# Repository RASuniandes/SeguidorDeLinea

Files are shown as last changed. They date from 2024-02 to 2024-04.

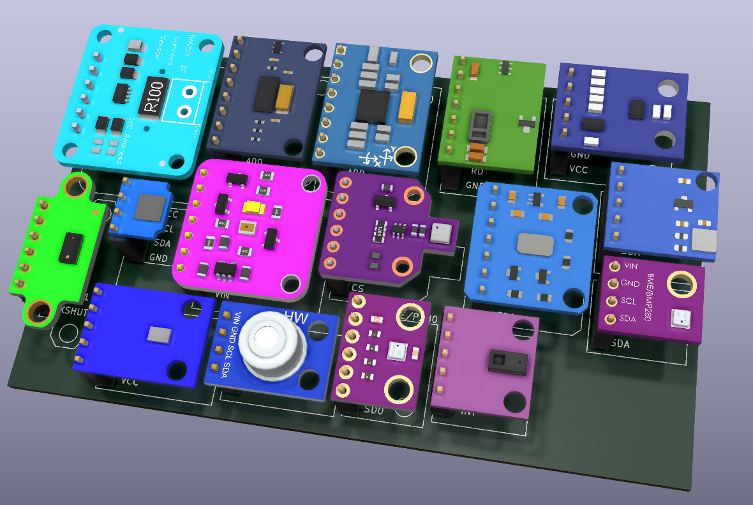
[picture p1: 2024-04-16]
PCB/librerias/librerias/usini_kicad_sensors-main/usini_kicad_sensors-main/sources/images/3D.png

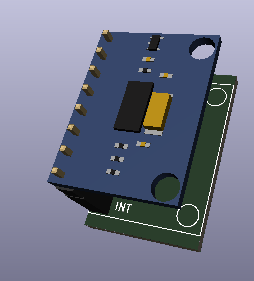
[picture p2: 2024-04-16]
PCB/librerias/librerias/usini_kicad_sensors-main/usini_kicad_sensors-main/sources/fusion360/adxl345.png

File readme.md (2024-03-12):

# Seguidor de linea
## Equipo 2024-1:
- Sergio Mora (SerAle25)
- Mateo López (Mateo-Lopez83)
- Alejandro Alvernia (AlejandroAAL)
- Laura Avelino (Lauraavelin)
- Valentina Romo ()
- Juan Felipe Ángulo (JuanFelipeAngulo)
- Mariana Vanoy (i4d1luc)
En rotación Valentina Arenas (Con interés de aprender temas de diseño mecánico e IMEC)

**Este es el equipo para 2024-1**

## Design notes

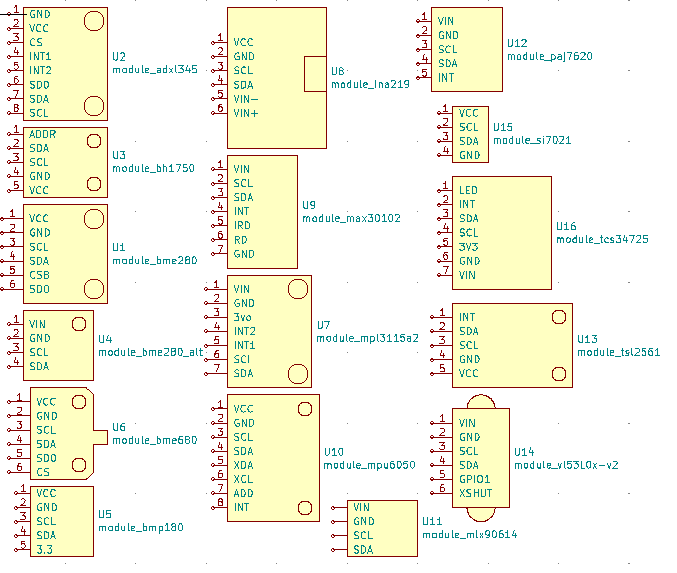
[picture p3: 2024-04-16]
PCB/librerias/librerias/usini_kicad_sensors-main/usini_kicad_sensors-main/sources/images/schematics.png

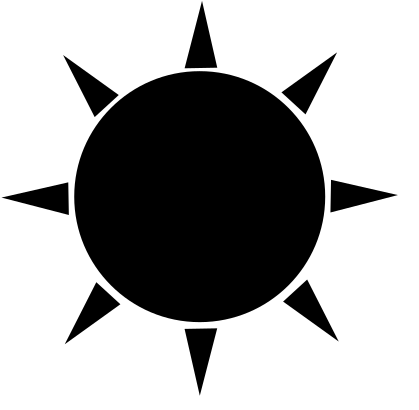
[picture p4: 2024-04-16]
PCB/librerias/librerias/usini_kicad_sensors-main/usini_kicad_sensors-main/sources/images/light.png

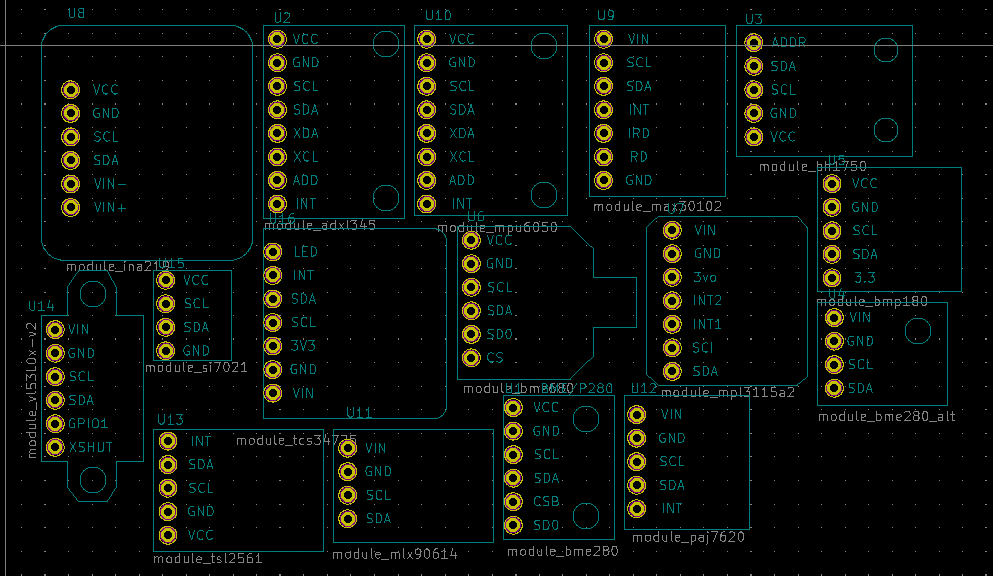
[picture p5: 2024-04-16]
PCB/librerias/librerias/usini_kicad_sensors-main/usini_kicad_sensors-main/sources/images/pcb.png

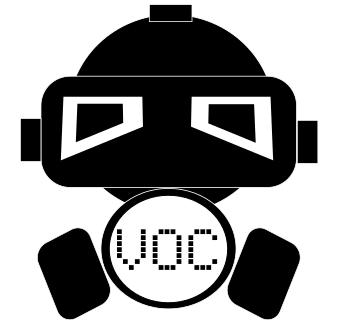
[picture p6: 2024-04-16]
PCB/librerias/librerias/usini_kicad_sensors-main/usini_kicad_sensors-main/sources/images/gas.png

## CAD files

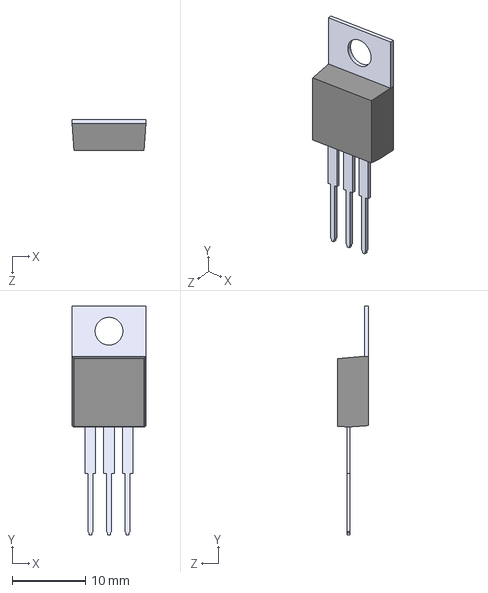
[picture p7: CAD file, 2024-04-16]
PCB/librerias/librerias/LM7805CT_NOPB/LM7805CT_NOPB.step
10.2 x 31.2 x 4.20 mm

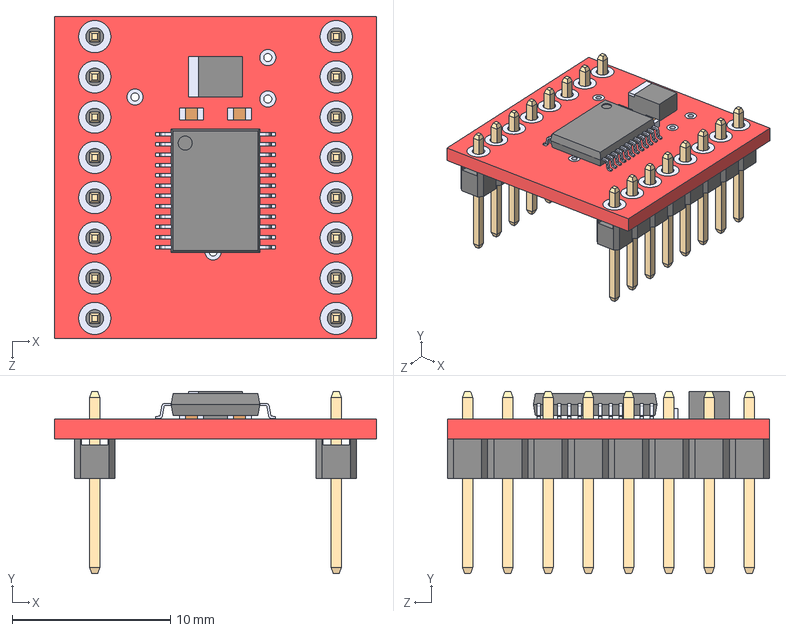
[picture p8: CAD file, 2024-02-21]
PCB/librerias/librerias/ROB-14450/ROB-14450.step
20.3 x 11.5 x 20.3 mm

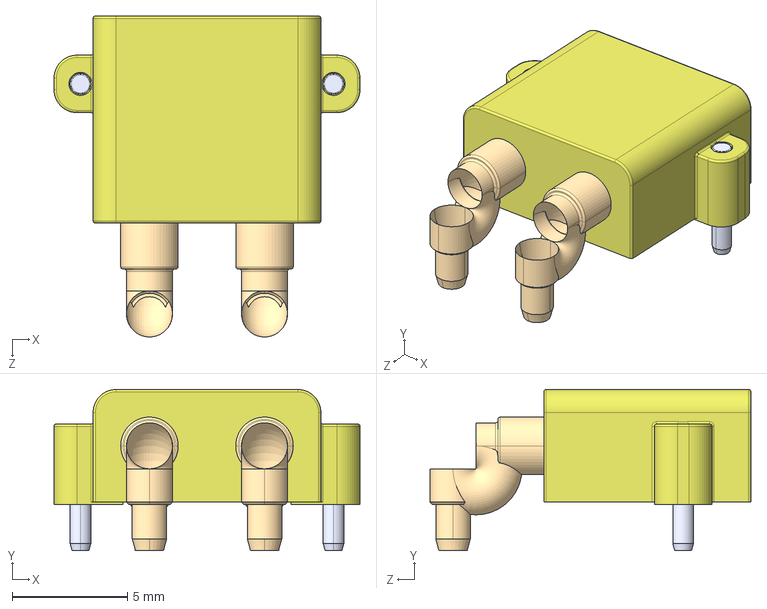
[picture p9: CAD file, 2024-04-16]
PCB/librerias/librerias/XT30PW-M/XT30PW-M.step
13.3 x 7.00 x 14.0 mm

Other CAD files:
PCB/librerias/librerias/usini_kicad_sensors-main/usini_kicad_sensors-main/sources/fusion360/MPL3115A2.f3d
PCB/librerias/librerias/usini_kicad_sensors-main/usini_kicad_sensors-main/sources/fusion360/PAJ7620.f3d
PCB/librerias/librerias/usini_kicad_sensors-main/usini_kicad_sensors-main/sources/fusion360/adxl345.f3d
PCB/librerias/librerias/usini_kicad_sensors-main/usini_kicad_sensors-main/sources/fusion360/audio_3.5mm_trrs.f3d
PCB/librerias/librerias/usini_kicad_sensors-main/usini_kicad_sensors-main/sources/fusion360/bmp180.f3d
PCB/librerias/librerias/usini_kicad_sensors-main/usini_kicad_sensors-main/sources/fusion360/module_si7021.f3d
PCB/librerias/librerias/usini_kicad_sensors-main/usini_kicad_sensors-main/sources/fusion360/tsl2561.f3d

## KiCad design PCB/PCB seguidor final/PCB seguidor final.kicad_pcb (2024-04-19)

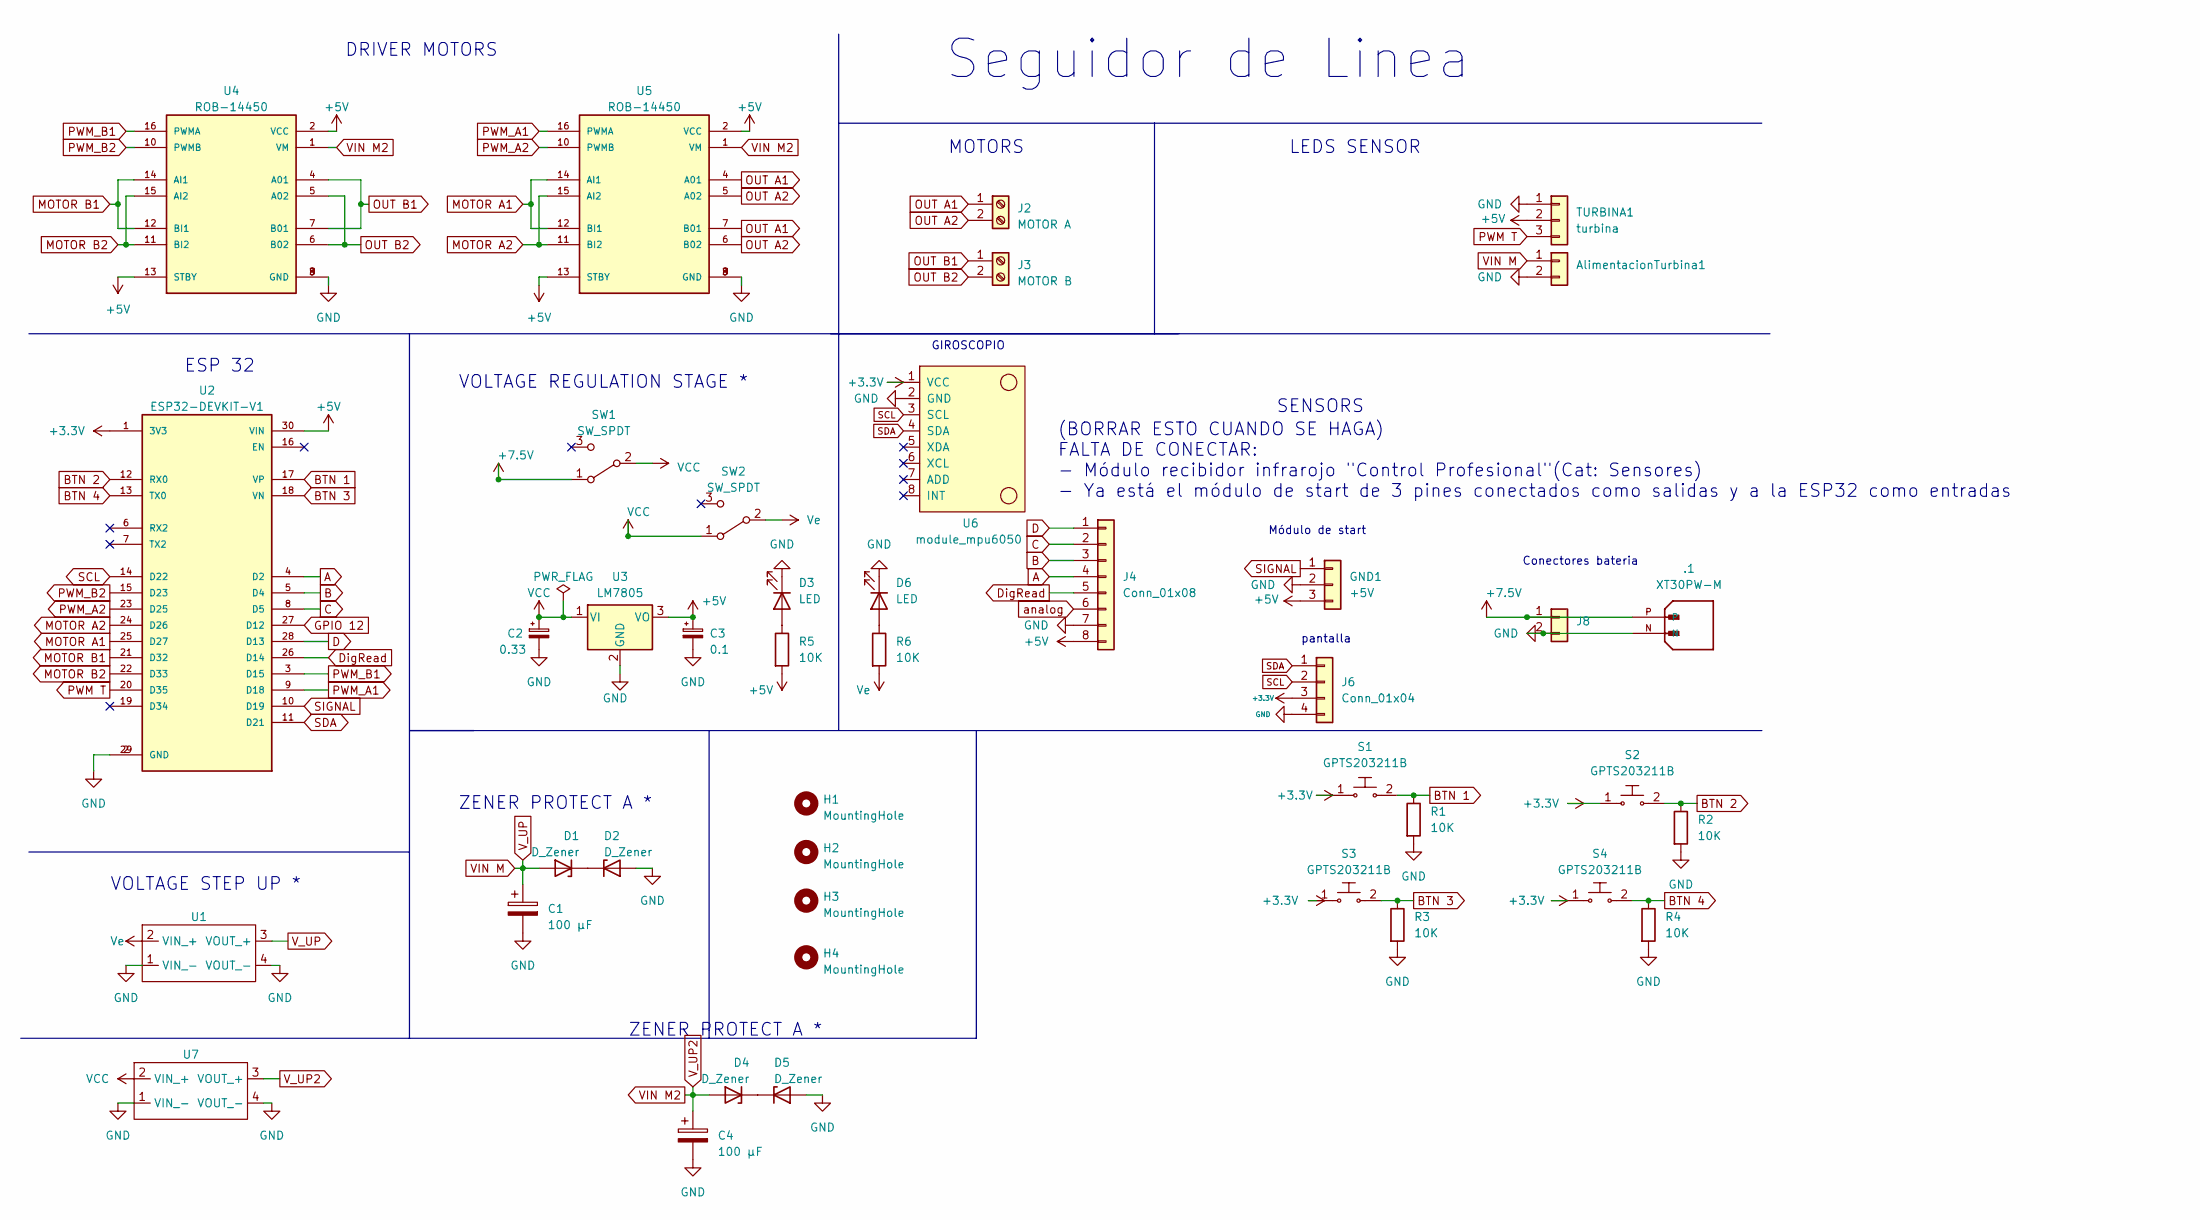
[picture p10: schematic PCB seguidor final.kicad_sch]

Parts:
.1: XT30PW-M; AMASS_XT30U-F_1x02_P5.0mm_Vertical; PARTREV 1.2
AlimentacionTurbina1: PinHeader_1x02_P2.54mm_Vertical
C1, C4: 100 μF; CP_Elec_6.3x5.9
C2: 0.33; CP_Elec_6.3x5.9
C3: 0.1; CP_Elec_6.3x5.9
D1, D2, D4, D5: D_Zener; D_A-405_P7.62mm_Horizontal
D3, D6: LED; LED_miniPLCC_2315_Handsoldering
GND1: +5V; PinHeader_1x03_P2.54mm_Vertical
H1, H2, H3, H4: MountingHole; MountingHole_3.2mm_M3_Pad_Via
J2: MOTOR A; TerminalBlock_4Ucon_1x02_P3.50mm_Horizontal
J3: MOTOR B; TerminalBlock_4Ucon_1x02_P3.50mm_Horizontal
J4: Conn_01x08; PinHeader_1x08_P2.54mm_Vertical
J6: Conn_01x04; 128x64OLED
J8: PinHeader_1x02_P2.54mm_Vertical
R1, R2, R3, R4, R5, R6: 10K; 0603
S1, S2, S3, S4: GPTS203211B; SW_PUSH_6mm_H5mm; MPN GPTS203211B
SW1, SW2: SW_SPDT; PinHeader_1x03_P2.54mm_Vertical
TURBINA1: turbina; PinHeader_1x03_P2.54mm_Vertical
U1, U7: MT3608-Module
U2: ESP32-DEVKIT-V1; MODULE_ESP32_DEVKIT_V1; PARTREV N/A
U3: LM7805; TO-252-2
U4, U5: ROB-14450; MODULE_ROB-14450; PARTREV 11-13-17
U6: module_mpu6050

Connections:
+3.3V: J6.3, S1.1, S2.1, S3.1, S4.1, U2.1 (3V3), U6.1 (VCC)
+5V: C3.1, GND1.3, J4.8, R5.2, TURBINA1.2, U2.30 (VIN), U3.3 (VO), U4.2 (VCC), U4.13 (STBY), U5.2 (VCC), U5.13 (STBY)
+7.5V: .1.P, J8.1, SW1.1 (A)
A: J4.4, U2.4 (D2)
B: J4.3, U2.5 (D4)
BTN 1: R1.1, S1.2, U2.17 (VP)
BTN 2: R2.1, S2.2, U2.12 (RX0)
BTN 3: R3.1, S3.2, U2.18 (VN)
BTN 4: R4.1, S4.2, U2.13 (TX0)
C: J4.2, U2.8 (D5)
D: J4.1, U2.28 (D13)
DigRead: J4.5, U2.26 (D14)
GND: .1.N, AlimentacionTurbina1.2, C1.2, C2.2, C3.2, C4.2, D2.2 (A), D3.1 (K), D5.2 (A), D6.1 (K), GND1.2, J4.7, J6.4, J8.2, R1.2, R2.2, R3.2, R4.2, TURBINA1.1, U1.1 (VIN_-), U1.4 (VOUT_-), U2.2 (GND), U2.29 (GND), U3.2 (GND), U4.3 (GND), U4.8 (GND), U4.9 (GND), U5.3 (GND), U5.8 (GND), U5.9 (GND), U6.2 (GND), U7.1 (VIN_-), U7.4 (VOUT_-)
GPIO 12: U2.27 (D12)
MOTOR A1: U2.25 (D27), U5.12 (BI1), U5.14 (AI1)
MOTOR A2: U2.24 (D26), U5.11 (BI2), U5.15 (AI2)
MOTOR B1: U2.21 (D32), U4.12 (BI1), U4.14 (AI1)
MOTOR B2: U2.22 (D33), U4.11 (BI2), U4.15 (AI2)
unnamed: D1.1 (K), D2.1 (K)
unnamed: D3.2 (A), R5.1
unnamed: D4.1 (K), D5.1 (K)
unnamed: D6.2 (A), R6.1
OUT A1: J2.1, U5.4 (A01), U5.7 (B01)
OUT A2: J2.2, U5.5 (A02), U5.6 (B02)
OUT B1: J3.1, U4.4 (A01), U4.7 (B01)
OUT B2: J3.2, U4.5 (A02), U4.6 (B02)
PWM T: TURBINA1.3, U2.20 (D35)
PWM_A1: U2.9 (D18), U5.16 (PWMA)
PWM_A2: U2.23 (D25), U5.10 (PWMB)
PWM_B1: U2.3 (D15), U4.16 (PWMA)
PWM_B2: U2.15 (D23), U4.10 (PWMB)
SCL: J6.2, U2.14 (D22), U6.3 (SCL)
SDA: J6.1, U2.11 (D21), U6.4 (SDA)
SIGNAL: GND1.1, U2.10 (D19)
VCC: C2.1, SW1.2 (B), SW2.1 (A), U3.1 (VI), U7.2 (VIN_+)
VIN M: AlimentacionTurbina1.1, C1.1, D1.2 (A), U1.3 (VOUT_+)
VIN M2: C4.1, D4.2 (A), U4.1 (VM), U5.1 (VM), U7.3 (VOUT_+)
Ve: R6.2, SW2.2 (B), U1.2 (VIN_+)
analog: J4.6

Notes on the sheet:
ZENER PROTECT A *
DRIVER MOTORS
Módulo de start
Seguidor de Linea
(BORRAR ESTO CUANDO SE HAGA) FALTA DE CONECTAR: - Módulo recibidor infrarojo "Control Profesional"(Cat: Sensores) - Ya está el módulo de start de 3 pines conectados como salidas y a la ESP32 como entradas
GIROSCOPIO
LEDS SENSOR
MOTORS
VOLTAGE STEP UP *
ESP 32
pantalla
SENSORS
Conectores bateria
VOLTAGE REGULATION STAGE *

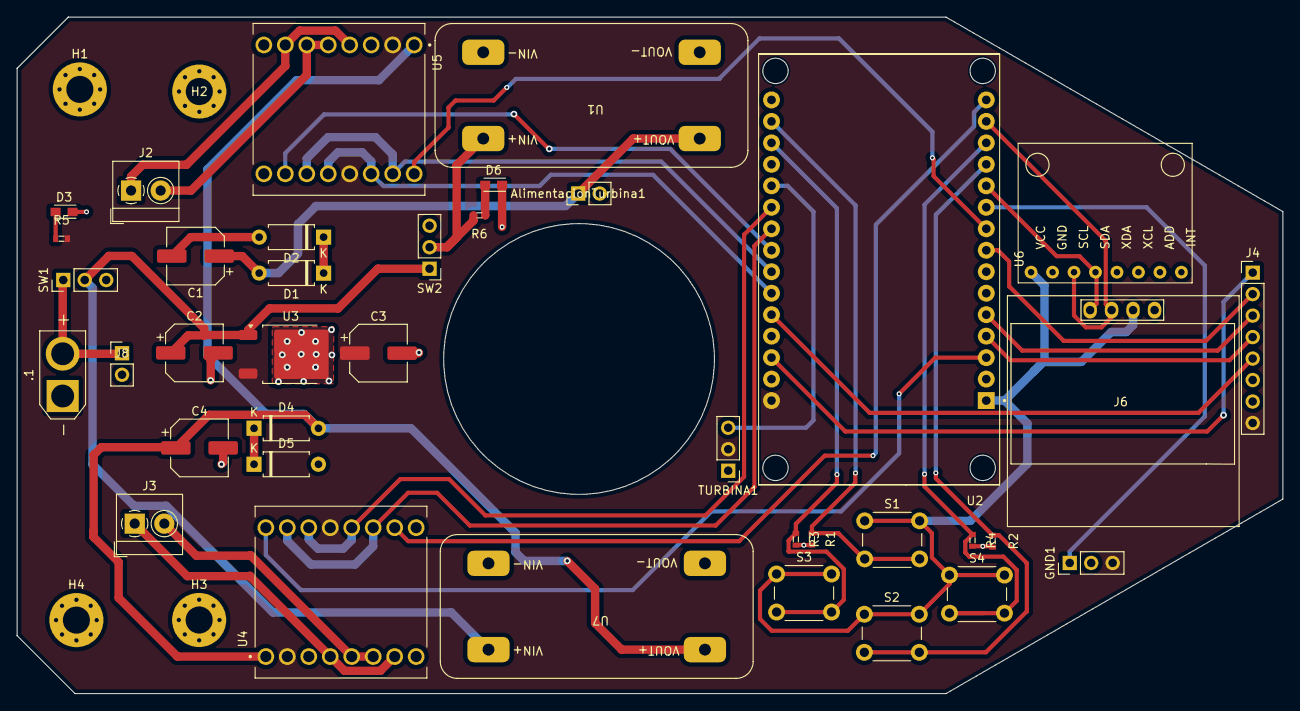
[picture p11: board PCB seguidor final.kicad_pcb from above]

Board: 2 copper layers, 149.7 x 80.0 mm, 42 parts (0 on the bottom side), 37 nets.

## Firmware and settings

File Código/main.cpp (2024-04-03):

#include <Arduino.h>

#define s1 17
#define s2 16
#define s3 15
#define s4 14
#define A0 20

int sensorPin = A0; //Seleccion de pin analógico a ser leido
int sensorValue = 0; //Variable que captura el valor analógico del sensor
int ValueFinal = 0; //Variable a ser mostrada en la OLED
int i=0; //Variable incremental para el muestreo de los sensores.
int buttonState=0;
int k=0; 
int valores[16];

// put function declarations here:
int myFunction(int, int);
void lectura(int k);

void setup() {
  // put your setup code here, to run once:
  Serial.begin(9600);
  pinMode(18,INPUT);
  pinMode(s1,OUTPUT);
  pinMode(s2,OUTPUT);
  pinMode(s3,OUTPUT);
  pinMode(s4,OUTPUT);
 
}

void lectura (int k){
  switch (k)
  {
  case 15:
    Serial.println("15");
    digitalWrite(s1,LOW);
    digitalWrite(s2,LOW);
    digitalWrite(s3,LOW);
    digitalWrite(s4,LOW);
    break;
  case 14:
    Serial.println("14");
    digitalWrite(s1,HIGH);
    digitalWrite(s2,LOW);
    digitalWrite(s3,LOW);
    digitalWrite(s4,LOW);
    break;
  case 13:
    Serial.println("13");
    digitalWrite(s1,LOW);
    digitalWrite(s2,HIGH);
    digitalWrite(s3,LOW);
    digitalWrite(s4,LOW);
    break;
  case 12:
    Serial.println("12");
    digitalWrite(s1,HIGH);
    digitalWrite(s2,HIGH);
    digitalWrite(s3,LOW);
    digitalWrite(s4,LOW);
    break;
  case 11:
    Serial.println("11");
    digitalWrite(s1,LOW);
    digitalWrite(s2,LOW);
    digitalWrite(s3,HIGH);
    digitalWrite(s4,LOW);
    break;
  case 10:
    Serial.println("10");
    digitalWrite(s1,HIGH);
    digitalWrite(s2,LOW);
    digitalWrite(s3,HIGH);
    digitalWrite(s4,LOW);
    break;
  case 9:
    Serial.println("9");
    digitalWrite(s1,LOW);
    digitalWrite(s2,HIGH);
    digitalWrite(s3,HIGH);
    digitalWrite(s4,LOW);
    break;
  case 8:
    Serial.println("8");
    digitalWrite(s1,HIGH);
    digitalWrite(s2,HIGH);
    digitalWrite(s3,HIGH);
    digitalWrite(s4,LOW);
    break;
  case 7:
    Serial.println("7");
    digitalWrite(s1,LOW);
    digitalWrite(s2,LOW);
    digitalWrite(s3,LOW);
    digitalWrite(s4,HIGH);
    break;
  case 6:
    Serial.println("6");
    digitalWrite(s1,HIGH);
    digitalWrite(s2,LOW);
    digitalWrite(s3,LOW);
    digitalWrite(s4,HIGH);
    break;
  case 5:
    Serial.println("5");
    digitalWrite(s1,LOW);
    digitalWrite(s2,HIGH);
    digitalWrite(s3,LOW);
    digitalWrite(s4,HIGH);
    break;
  case 4:
    Serial.println("4");
    digitalWrite(s1,HIGH);
    digitalWrite(s2,HIGH);
    digitalWrite(s3,LOW);
    digitalWrite(s4,HIGH);
    break;
  case 3:
    Serial.println("3");
    digitalWrite(s1,LOW);
    digitalWrite(s2,LOW);
    digitalWrite(s3,HIGH);
    digitalWrite(s4,HIGH);
    break;
  case 2:
    Serial.println("2");
    digitalWrite(s1,HIGH);
    digitalWrite(s2,LOW);
    digitalWrite(s3,HIGH);
    digitalWrite(s4,HIGH);
    break;
  case 1:
    Serial.println("1");
    digitalWrite(s1,LOW);
    digitalWrite(s2,HIGH);
    digitalWrite(s3,HIGH);
    digitalWrite(s4,HIGH);
    break;
  case 0:
    Serial.println("0");
    digitalWrite(s1,HIGH);
    digitalWrite(s2,HIGH);
    digitalWrite(s3,HIGH);
    digitalWrite(s4,HIGH);
    break;
  }

  
}
void loop() {
  for(i=15; i>=0; i--) {
    Serial.println(i);
    lectura(i);
    sensorValue = digitalRead(sensorPin);
    Serial.println("valor es"+ (String)sensorValue);
    ValueFinal=sensorValue;
    valores[15-i] = ValueFinal;
    Serial.println(valores[15-i]);
    delay(500);
    
  }
  // put your main code here, to run repeatedly:
}


// put function definitions here:

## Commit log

2024-02-21 CAmbios del equiipo de mariana para desarrollo PCB
    [ROB-14450.step, Seguidor de linea.kicad_pcb, Seguidor de linea.kicad_sch]
2024-02-23 Puse un punto
    [Seguidor de linea.kicad_sch]
2024-02-23 Update Seguidor de linea.kicad_sch
    creo que ya
    [Seguidor de linea.kicad_sch]
2024-02-23 Ping Pong
    Ping Pong Tutorial GH
    [Seguidor de linea.kicad_sch]
2024-02-23 Segundo Driver de motor añadido
    -Termine lo del segundo driver de motor
    -Acomode el esquema
    [Seguidor de linea.kicad_sch]
2024-02-23 Módulo start
    Agregué el módulo de start a sensors, con un total de 3 pines para signal, VCC y Gnd
    [Seguidor de linea.kicad_sch]
2024-02-23 Update Seguidor de linea.kicad_sch
    [Seguidor de linea.kicad_sch]
2024-03-01 xd
    xd
    [Seguidor de linea.kicad_sch]
2024-03-08 Add files via upload
    este es el archivo más actualizado para la pcb, se irá trabajando sobre este. Es necesario completar con los componentes que hagan falta e ir agregando las respectivas huellas para cada uno
2024-03-12 Create Seguidor de línea final
2024-04-16 Porfin trato de hacer algo xd
    [PCB seguidor final.kicad_pcb, PCB seguidor final.kicad_sch]
2024-04-16 mas librerias
    [familylist_refdes.csv]
2024-04-16 las huellas FUNCIONAN
    [PCB seguidor final.kicad_pcb, PCB seguidor final.kicad_sch, familylist_refdes.csv]
2024-04-17 Acabada(esperando corrección)
    [PCB seguidor final.kicad_pcb, PCB seguidor final.kicad_sch]
2024-04-17 Algunas correcciones hechas
    Flata poner led de encendido general y turbina, hacerla un poco mas estetica
    [PCB seguidor final.kicad_pcb, PCB seguidor final.kicad_sch]
2024-04-19 Correcciones hechas
    [PCB seguidor final.kicad_pcb, PCB seguidor final.kicad_sch]
